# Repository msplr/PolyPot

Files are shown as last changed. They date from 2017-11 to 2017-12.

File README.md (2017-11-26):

# PolyPot Smart Flower Pot

PolyPot is the result of a semester project from the course *Products Design & System Engineering*.
PolyPot is a connected flower pot that automatically waters your plant and lets you monitor it's health remotely.

The microcontroller is an ESP32 and it has sensors for soil moisture, temperature, luminosity and water level connected to it.

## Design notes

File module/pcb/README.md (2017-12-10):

# PolyPot Control Module PCB

## Issues

- Button gpio 23 does not allow wakeup from deepsleep -> connect to IO15
- Soil moisture sensor pinout is wrong. FIX THE CABLE BEFORE CONNECTING!
- IO12 is not connected to SENSOR_ENn PMOS (typo in signal name)
- IO12 must not be pulled up during boot -> use IO25
- R1 and R11 need to be ~120 Ohm to have higher LED brightness
- Footprint of buttons RESET and PROG is too small

## Images
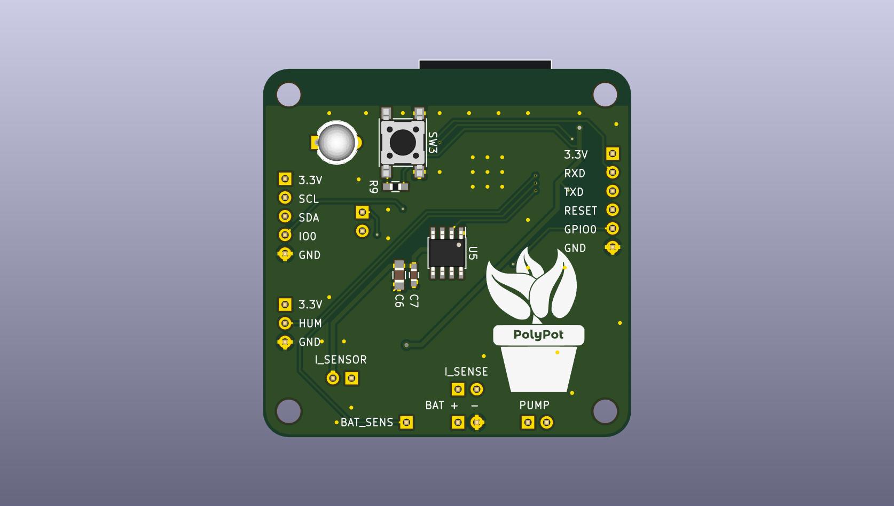
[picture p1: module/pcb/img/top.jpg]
Board Top

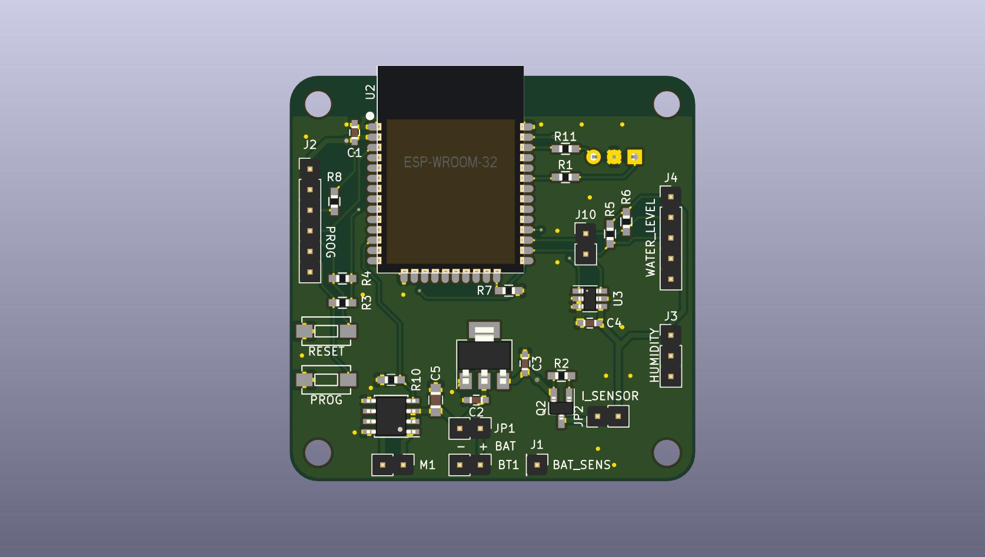
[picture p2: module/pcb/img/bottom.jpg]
Board Bottom

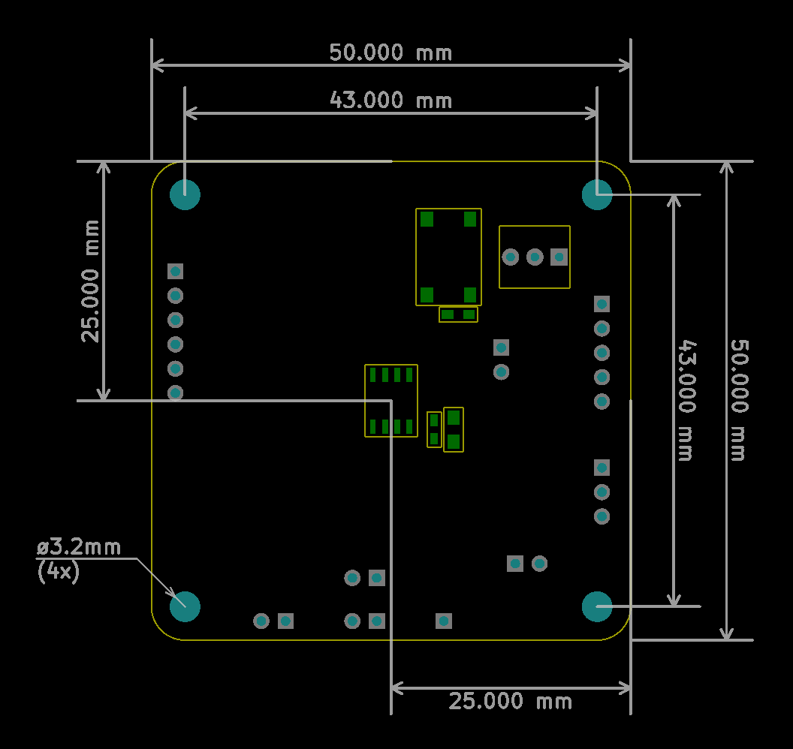
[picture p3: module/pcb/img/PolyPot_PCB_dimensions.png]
Board Dimensions


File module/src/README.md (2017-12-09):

# PolyPot control module source code

## Deploying the code

Copy all necessary modules to the folder `/micropython-esp32/ports/esp32/modules/` in the micropython-esp32 repository.
Then rebuild the firmware:
```
make
make erase
make deploy
```

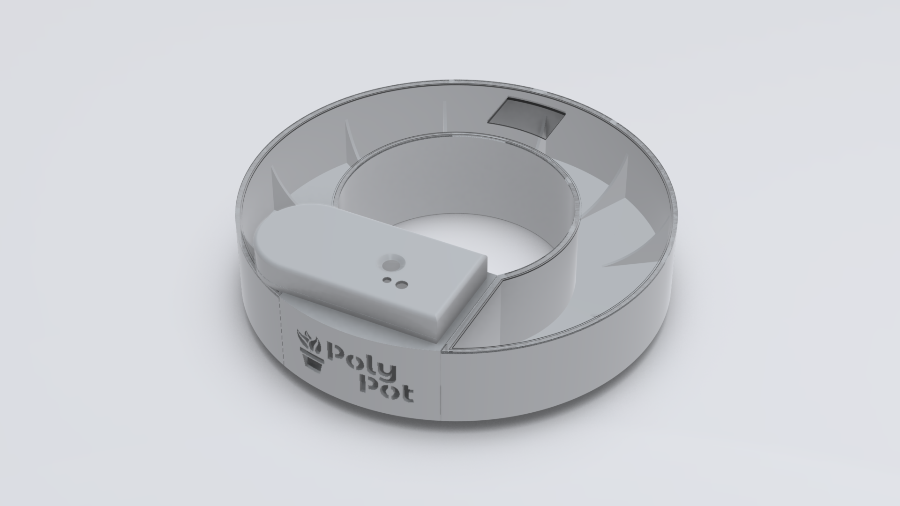
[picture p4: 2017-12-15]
mechanical/solidworks/POLYPOT.png

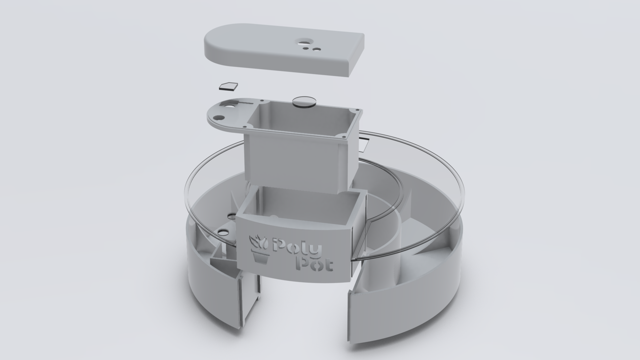
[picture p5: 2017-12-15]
mechanical/solidworks/POLYPOT_EXPLODED.png

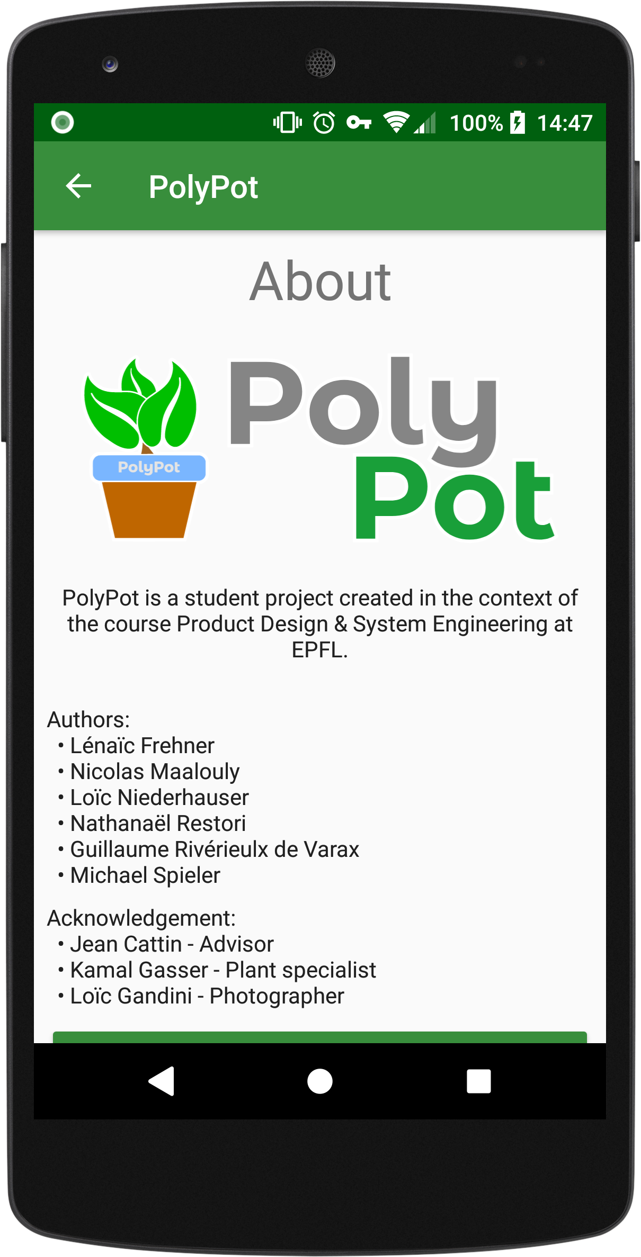
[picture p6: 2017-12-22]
graphics/screenshots/about.png

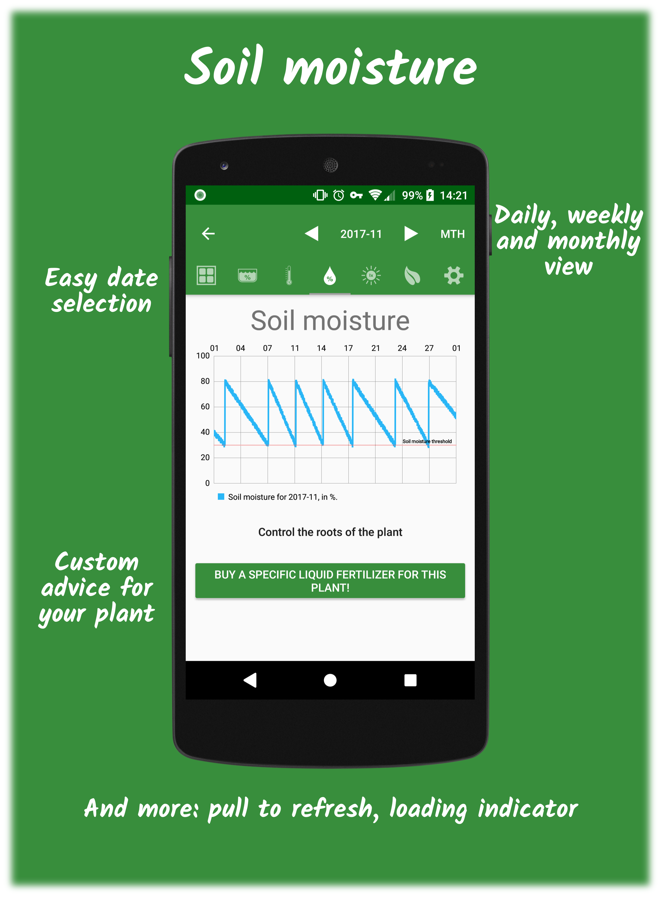
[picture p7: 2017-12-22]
graphics/screenshots/features_soil_moisture.png

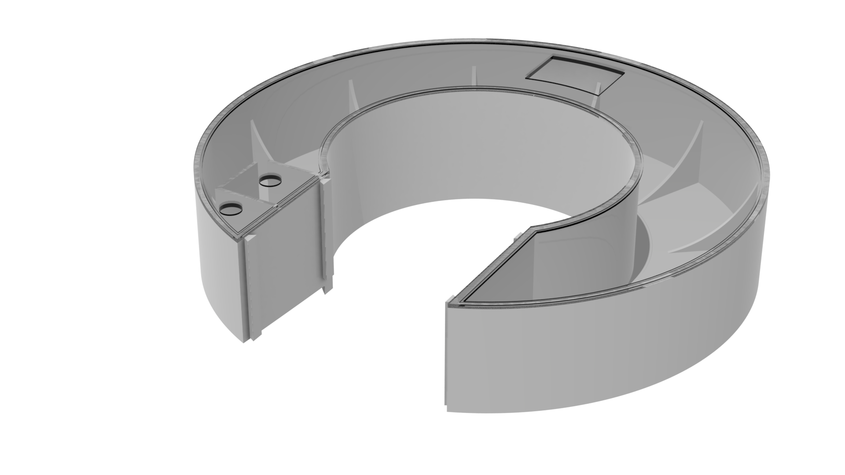
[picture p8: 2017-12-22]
graphics/rendering/water_tank.png

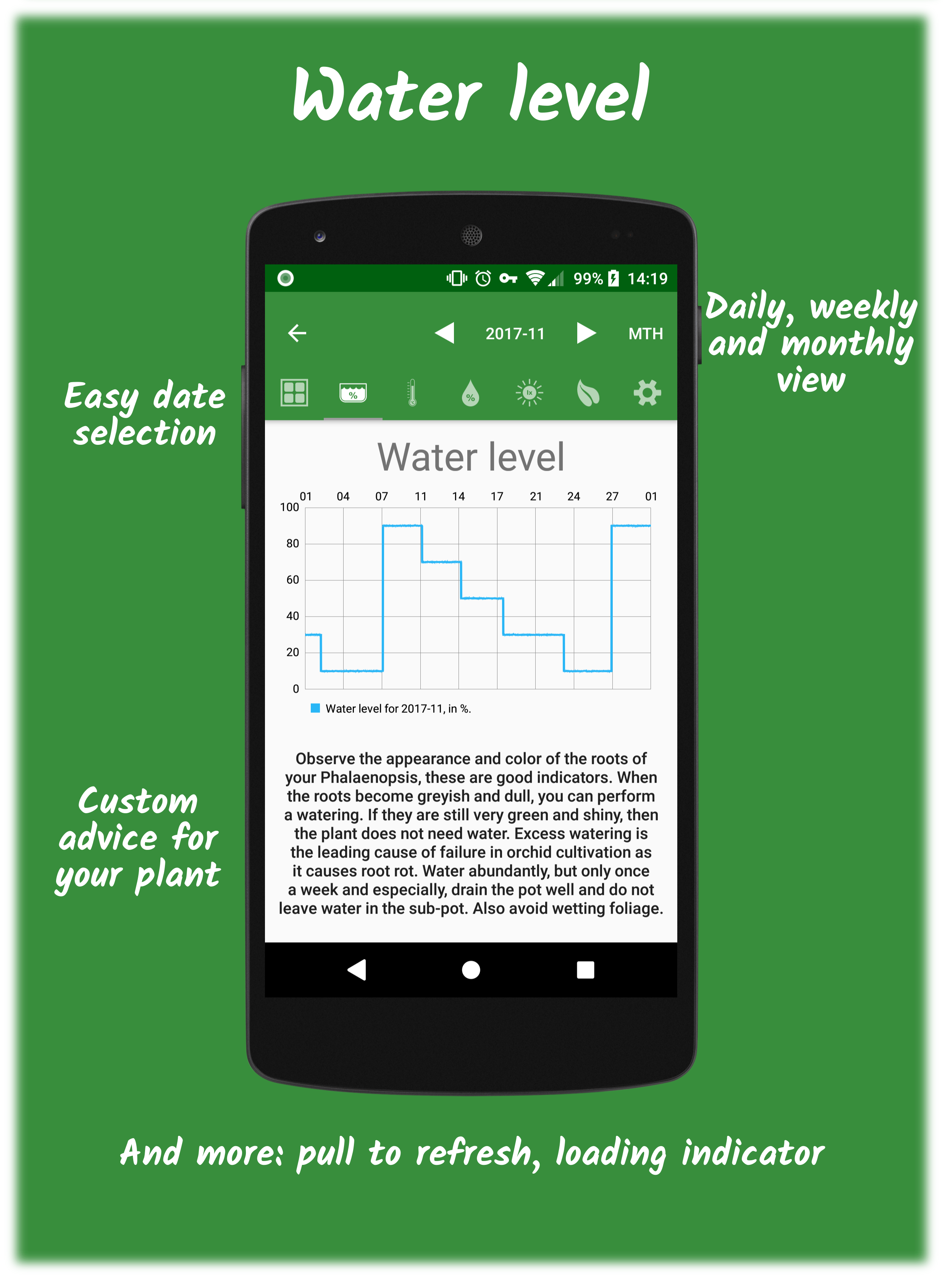
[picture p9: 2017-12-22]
graphics/screenshots/features_water_level.png

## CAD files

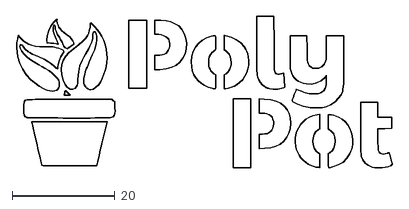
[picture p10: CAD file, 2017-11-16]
mechanical/dxf/logo-title-CAD.dxf
73.3 x 29.7

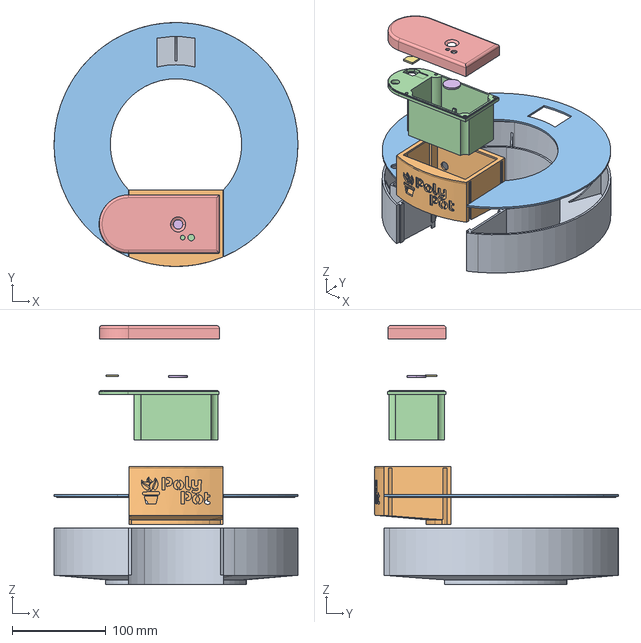
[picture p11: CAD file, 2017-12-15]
mechanical/step/POLYPOT_EXPLODED.stp
260.0 x 259.9 x 276.0 mm

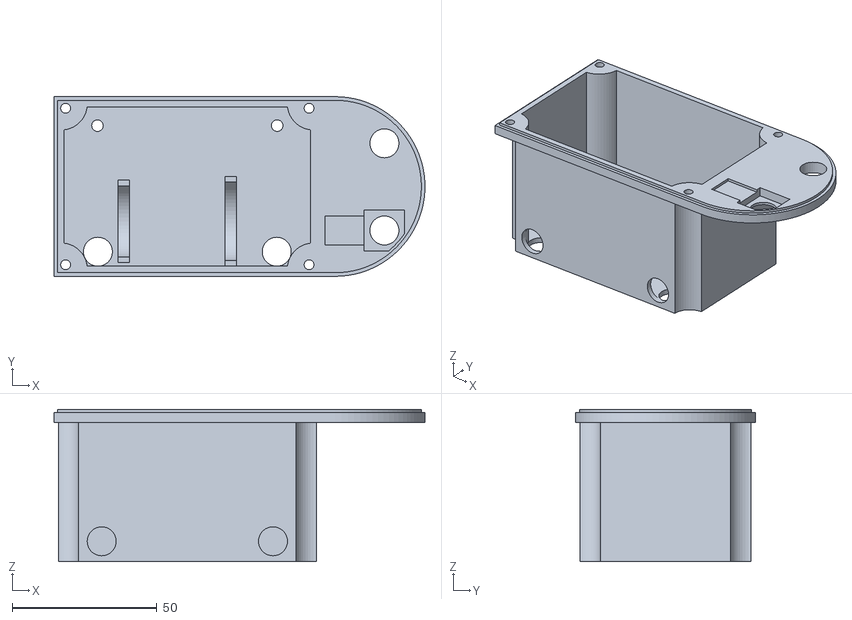
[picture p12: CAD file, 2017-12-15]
mechanical/stl/MODULE.stl
128.0 x 62.0 x 52.5

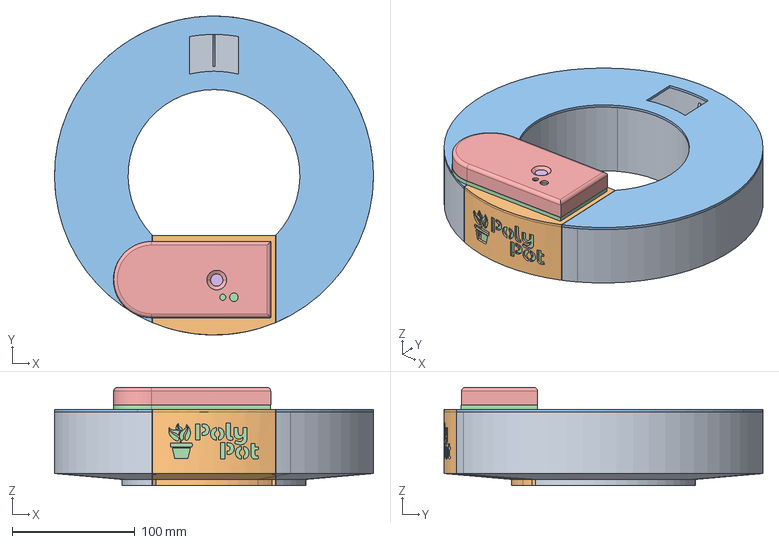
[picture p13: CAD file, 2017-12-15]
mechanical/step/POLYPOT.stp
260.0 x 260.0 x 80.0 mm

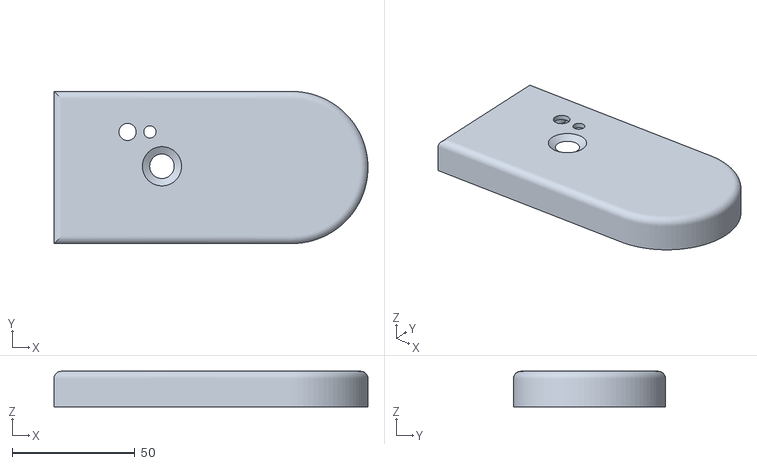
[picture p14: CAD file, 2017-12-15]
mechanical/stl/MODULE_LID.stl
128.0 x 62.0 x 14.5

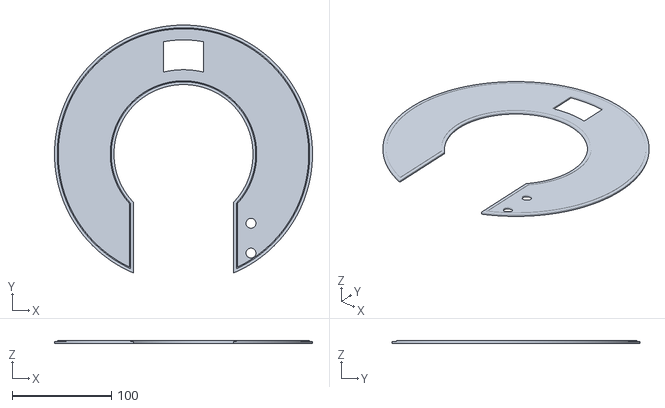
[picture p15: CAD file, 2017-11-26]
mechanical/stl/LID.stl
260.0 x 249.8 x 3.00

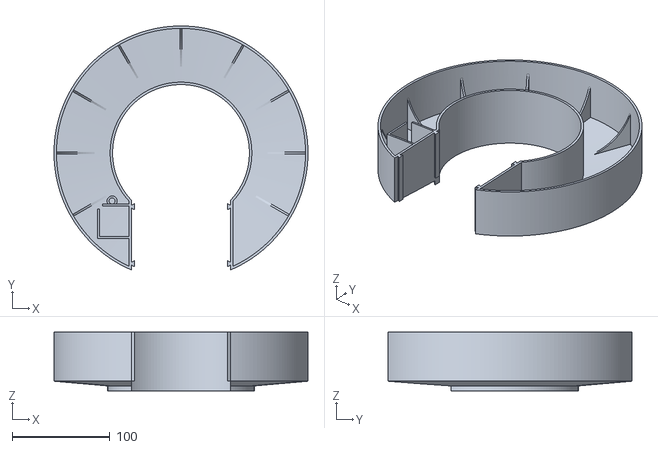
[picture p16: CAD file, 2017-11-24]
mechanical/stl/WATER_TANK.stl
260.0 x 249.8 x 60.0

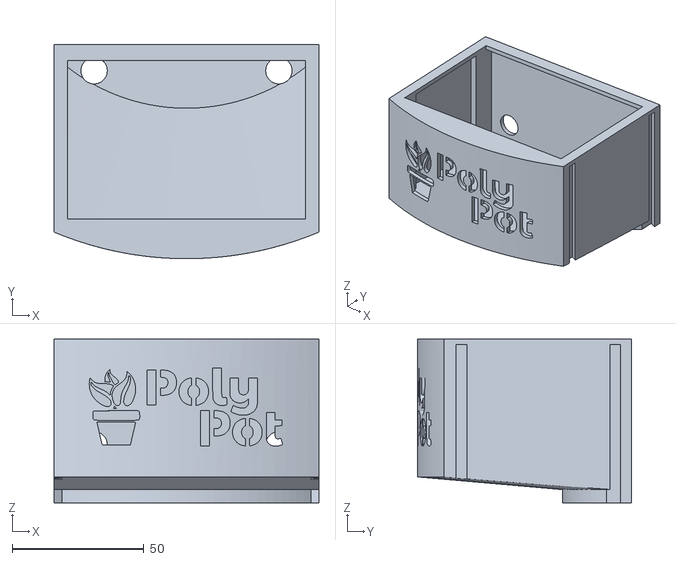
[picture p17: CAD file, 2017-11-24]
mechanical/stl/ADAPTER.stl
100.4 x 81.2 x 62.0

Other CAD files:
mechanical/catia/ADAPTER.CATPart
mechanical/catia/LID.CATPart
mechanical/catia/MODULE.CATPart
mechanical/catia/MODULE_LID.CATPart
mechanical/catia/POLYPOT.CATProduct
mechanical/catia/POLYPOT_EXPLODED.CATProduct
mechanical/catia/WATER_TANK.CATPart
mechanical/catia/WINDOW_LUMINOSITY.CATPart
mechanical/catia/WINDOW_TOF.CATPart
mechanical/dxf/LID.dxf

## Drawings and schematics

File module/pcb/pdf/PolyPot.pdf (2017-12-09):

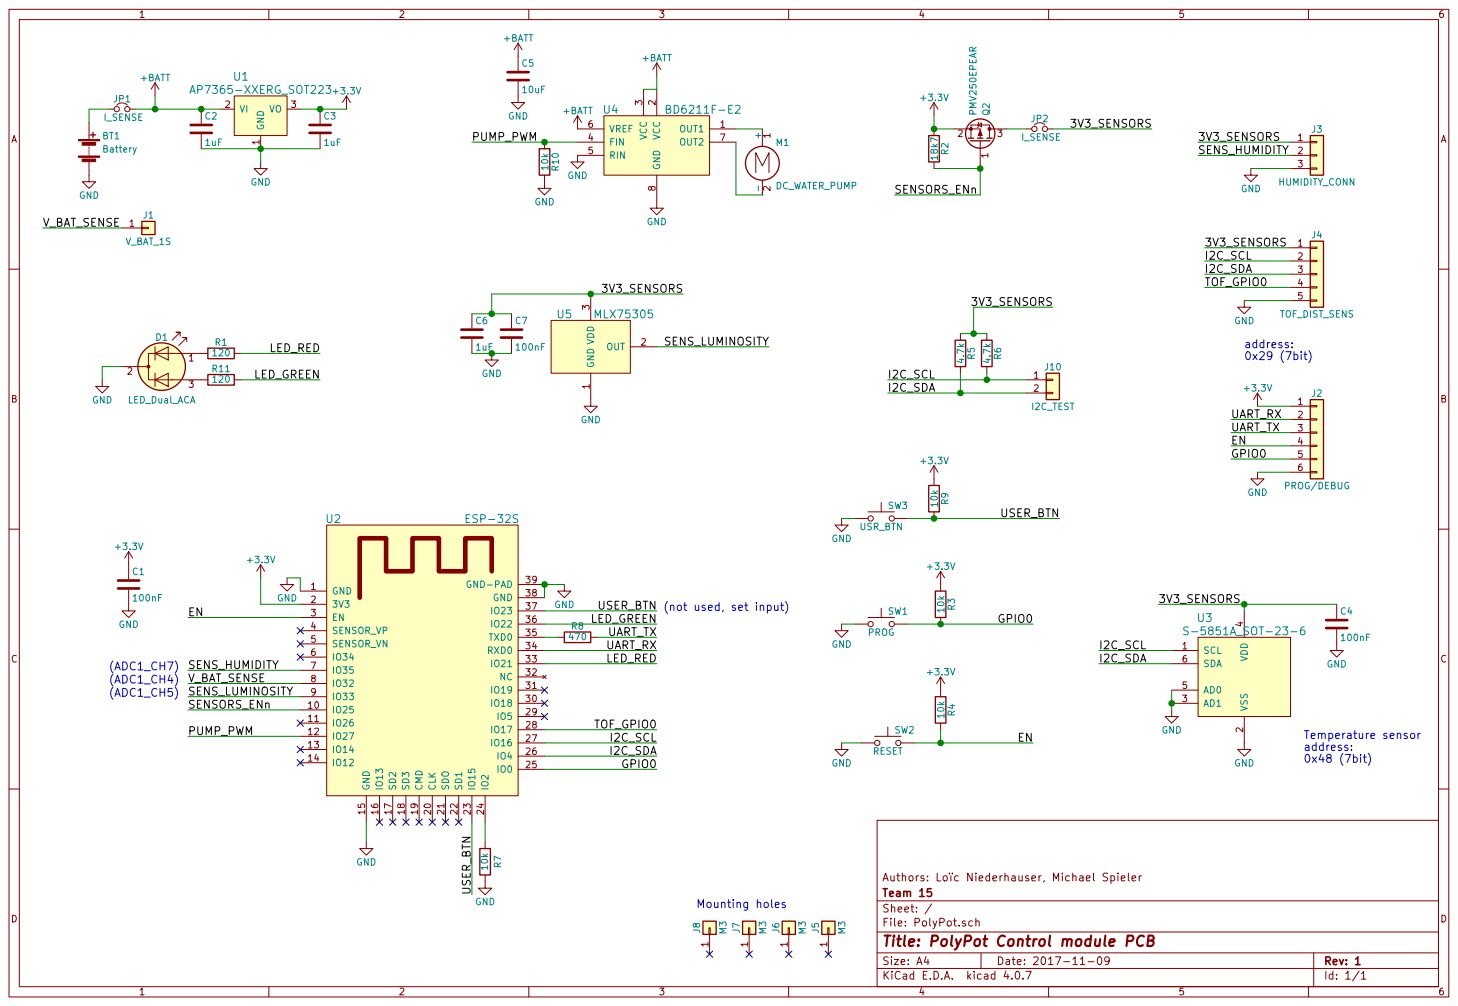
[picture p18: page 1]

3 FIN 4 RIN 5 VREF 6 OUT2 7 GND

(not used, set input)

File: PolyPot.sch Sheet: / Team 15 Authors: Loïc Niederhauser, Michael Spieler

Id: 1/1 Title: PolyPot Control module PCB

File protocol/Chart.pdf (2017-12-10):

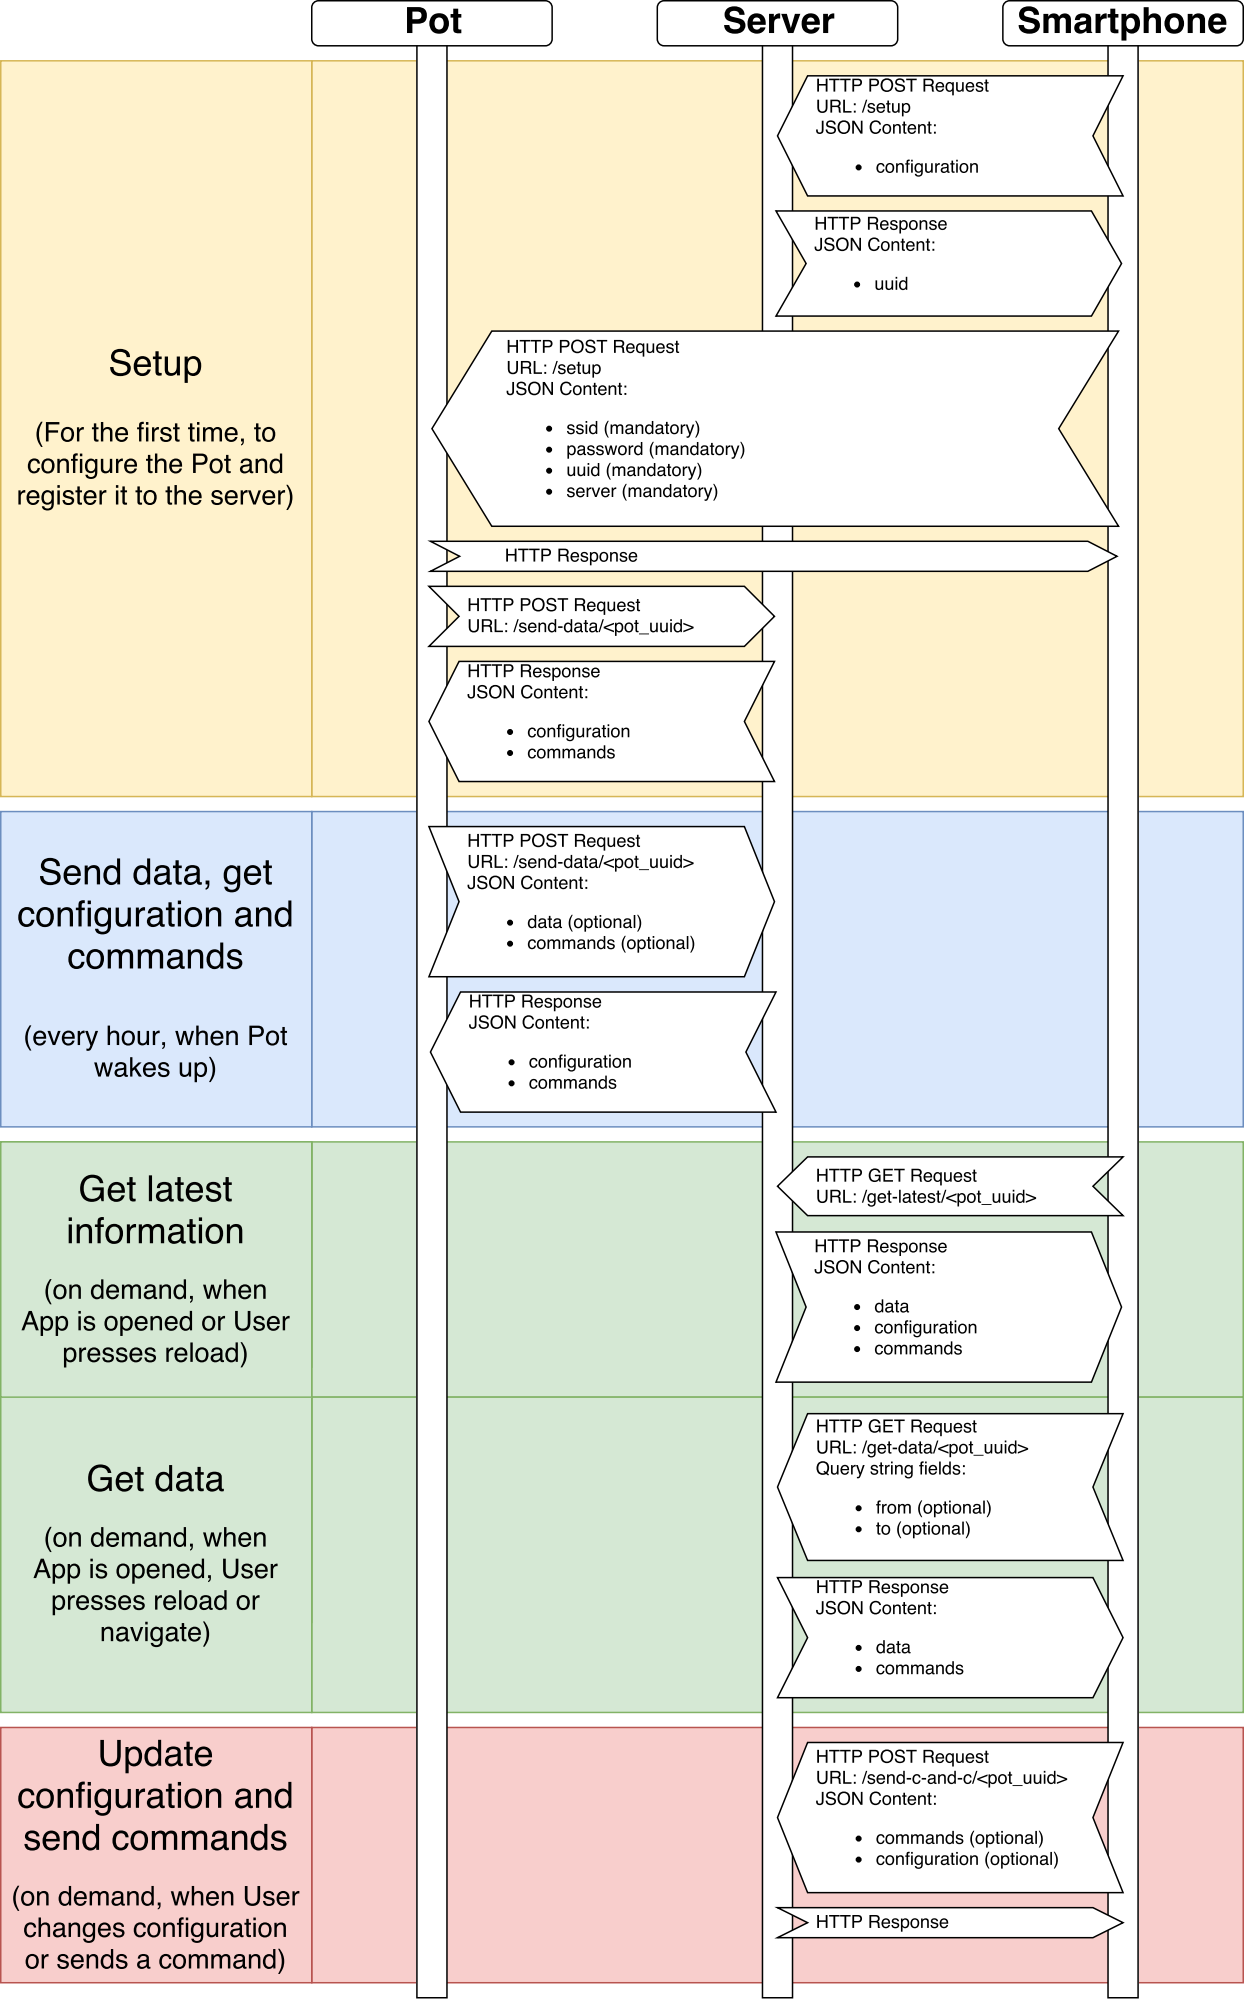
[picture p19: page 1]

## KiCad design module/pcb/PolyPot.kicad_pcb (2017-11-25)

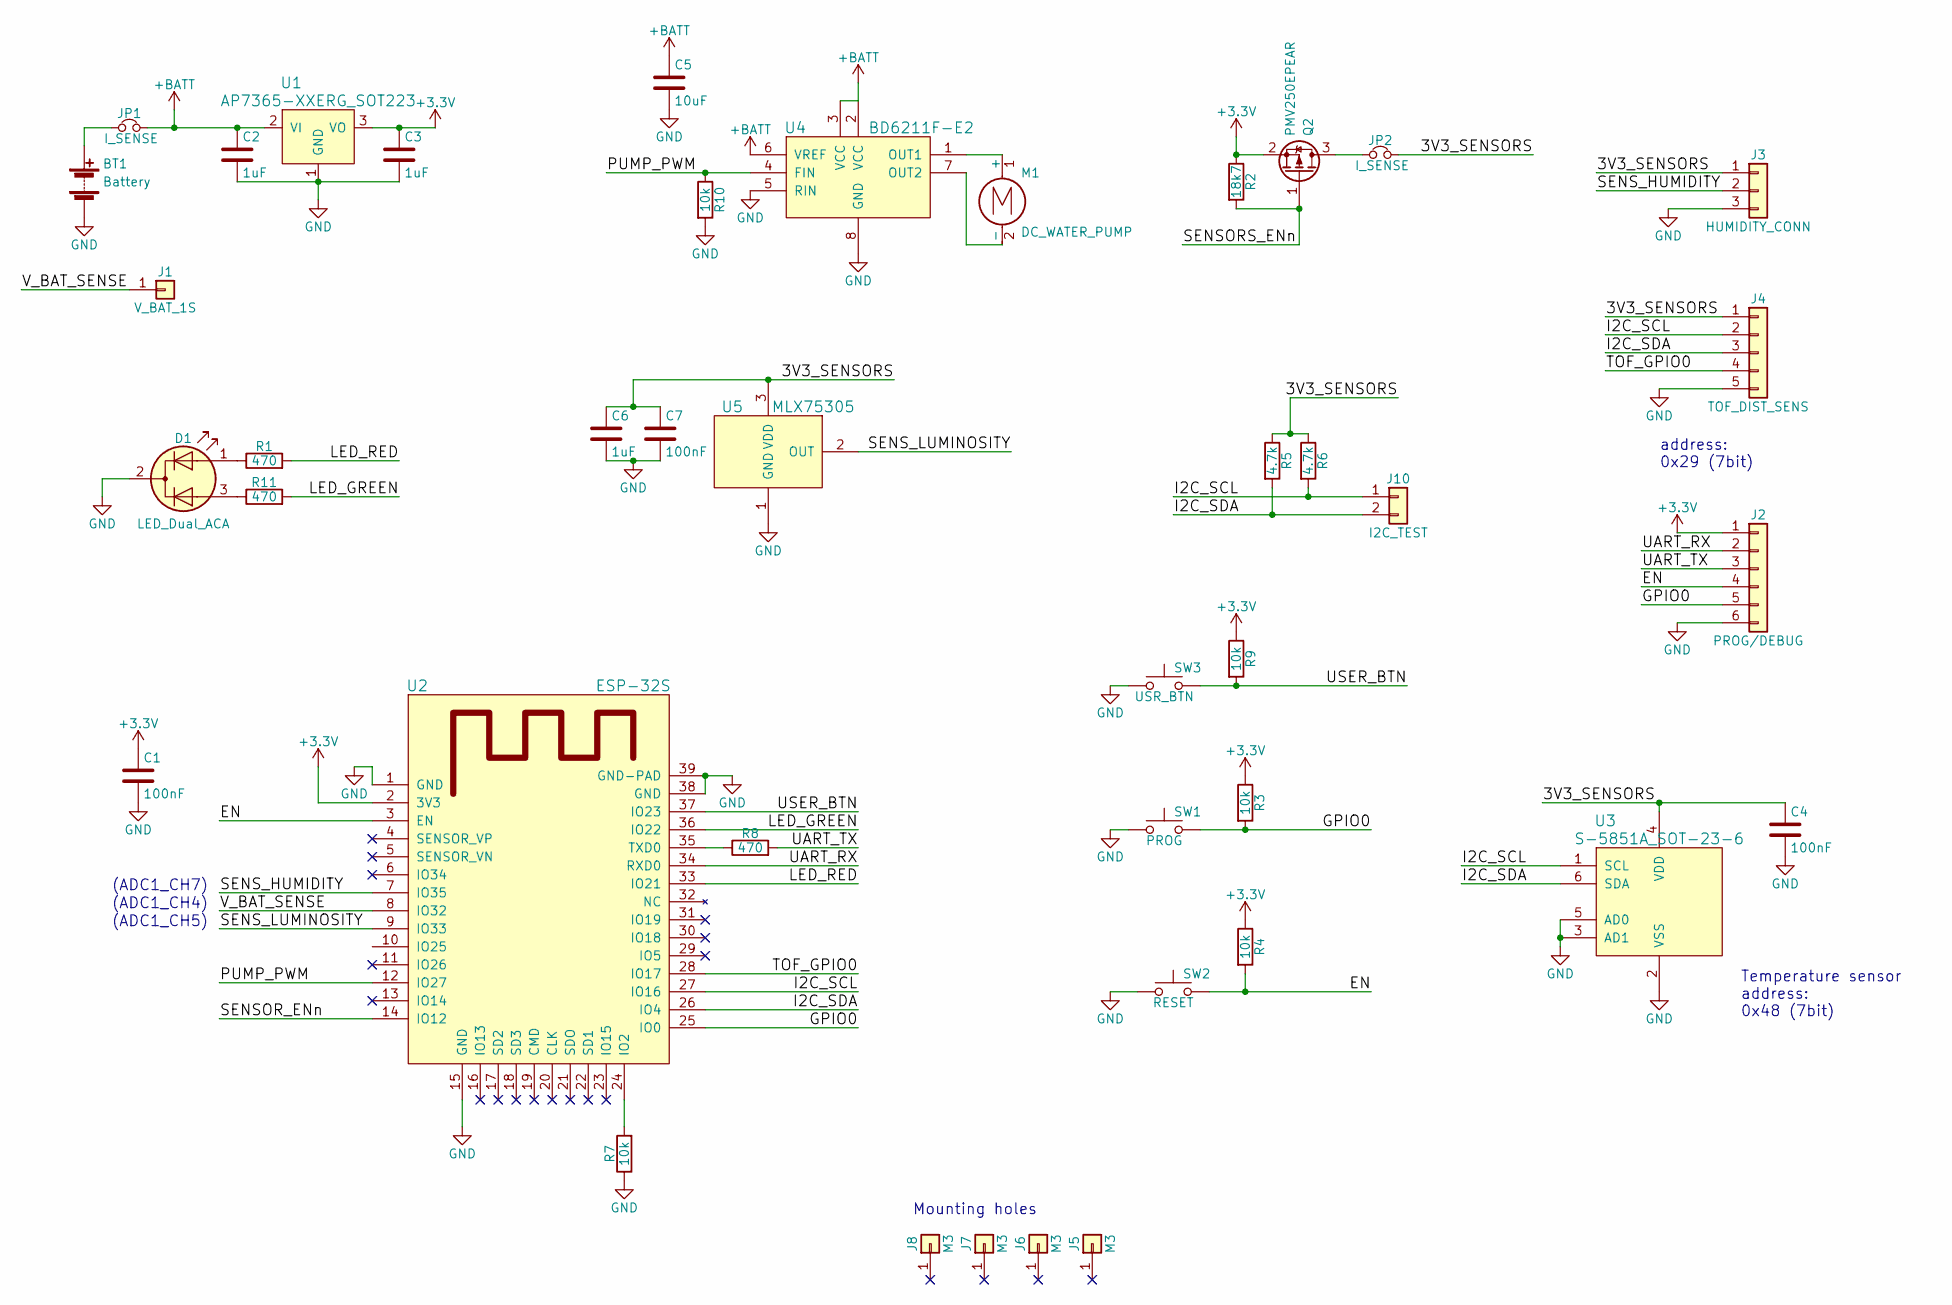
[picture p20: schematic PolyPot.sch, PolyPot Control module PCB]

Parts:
BT1: Battery; Pin_Header_Straight_1x02_Pitch2.54mm
C1, C4, C7: 100nF; C_0603_HandSoldering
C2, C3: 1uF; C_0603_HandSoldering
C5: 10uF; C_0805_HandSoldering
C6: 1uF; C_0805_HandSoldering
D1: LED_Dual_ACA; LED_D5.0mm-3
J1: V_BAT_1S; Pin_Header_Straight_1x01_Pitch2.54mm
J2: PROG/DEBUG; Pin_Header_Straight_1x06_Pitch2.54mm
J3: HUMIDITY_CONN; Pin_Header_Straight_1x03_Pitch2.54mm
J4: TOF_DIST_SENS; Pin_Header_Straight_1x05_Pitch2.54mm
J5, J6, J7, J8: M3; MountingHole_3.2mm_M3
J10: I2C_TEST; Pin_Header_Straight_1x02_Pitch2.54mm
JP1, JP2: I_SENSE; Pin_Header_Straight_1x02_Pitch2.54mm
M1: DC_WATER_PUMP; Pin_Header_Straight_1x02_Pitch2.54mm
Q2: PMV250EPEAR; SOT-23_Handsoldering
R1, R8, R11: 470; R_0603_HandSoldering
R2: 18k7; R_0603_HandSoldering
R3, R4, R7, R9, R10: 10k; R_0603_HandSoldering
R5, R6: 4.7k; R_0603_HandSoldering
SW1: PROG; SW_SPST_EVQPE1
SW2: RESET; SW_SPST_EVQPE1
SW3: USR_BTN; SW_SPST_PTS645
U1: AP7365-XXERG_SOT223; SOT-223
U2: ESP-32S
U3: S-5851A_SOT-23-6; SOT-23-6_Handsoldering
U4: BD6211F-E2; SOIC-8_3.9x4.9mm_Pitch1.27mm
U5: MLX75305; SOIC-8_3.9x4.9mm_Pitch1.27mm

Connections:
+3V3: C1.1, C3.1, J2.1, Q2.2 (S), R2.1, R3.1, R4.1, R9.1, U1.3 (VO), U2.2 (3V3)
+BATT: C2.1, C5.1, JP1.2, U1.2 (VI), U4.2 (VCC), U4.3 (VCC), U4.6 (VREF)
/3V3_SENSORS: C4.1, C6.1, C7.1, J3.1, J4.1, JP2.2, R5.1, R6.1, U3.4 (VDD), U5.3 (VDD)
/EN: J2.4, R4.2, SW2.2, U2.3 (EN)
/GPIO0: J2.5, R3.2, SW1.2, U2.25 (IO0)
/I2C_SCL: J4.2, J10.1, R6.2, U2.27 (IO16), U3.1 (SCL)
/I2C_SDA: J4.3, J10.2, R5.2, U2.26 (IO4), U3.6 (SDA)
/LED_GREEN: R11.2, U2.36 (IO22)
/LED_RED: R1.2, U2.33 (IO21)
/PUMP_PWM: R10.1, U2.12 (IO27), U4.4 (FIN)
/SENSORS_ENn: Q2.1 (G), R2.2
/SENS_HUMIDITY: J3.2, U2.7 (IO35)
/SENS_LUMINOSITY: U2.9 (IO33), U5.2 (OUT)
/TOF_GPIO0: J4.4, U2.28 (IO17)
/UART_RX: J2.2, U2.34 (RXD0)
/UART_TX: J2.3, R8.2
/USER_BTN: R9.2, SW3.2, U2.37 (IO23)
/V_BAT_SENSE: J1.1, U2.8 (IO32)
GND: BT1.2 (-), C1.2, C2.2, C3.2, C4.2, C5.2, C6.2, C7.2, D1.2 (K), J2.6, J3.3, J4.5, R7.1, R10.2, SW1.1, SW2.1, SW3.1, U1.1 (GND), U2.1 (GND), U2.15 (GND), U2.38 (GND), U2.39 (GND-PAD), U3.2 (VSS), U3.3 (AD1), U3.5 (AD0), U4.5 (RIN), U4.8 (GND), U5.1 (GND)
unnamed: BT1.1 (+), JP1.1
unnamed: D1.1 (A1), R1.1
unnamed: D1.3 (A2), R11.1
unnamed: JP2.1, Q2.3 (D)
unnamed: M1.1 (+), U4.1 (OUT1)
unnamed: M1.2 (-), U4.7 (OUT2)
unnamed: R7.2, U2.24 (IO2)
unnamed: R8.1, U2.35 (TXD0)

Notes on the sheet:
address: 0x29 (7bit)
Temperature sensor address: 0x48 (7bit)
Mounting holes
(ADC1_CH4)
(ADC1_CH5)
(ADC1_CH7)

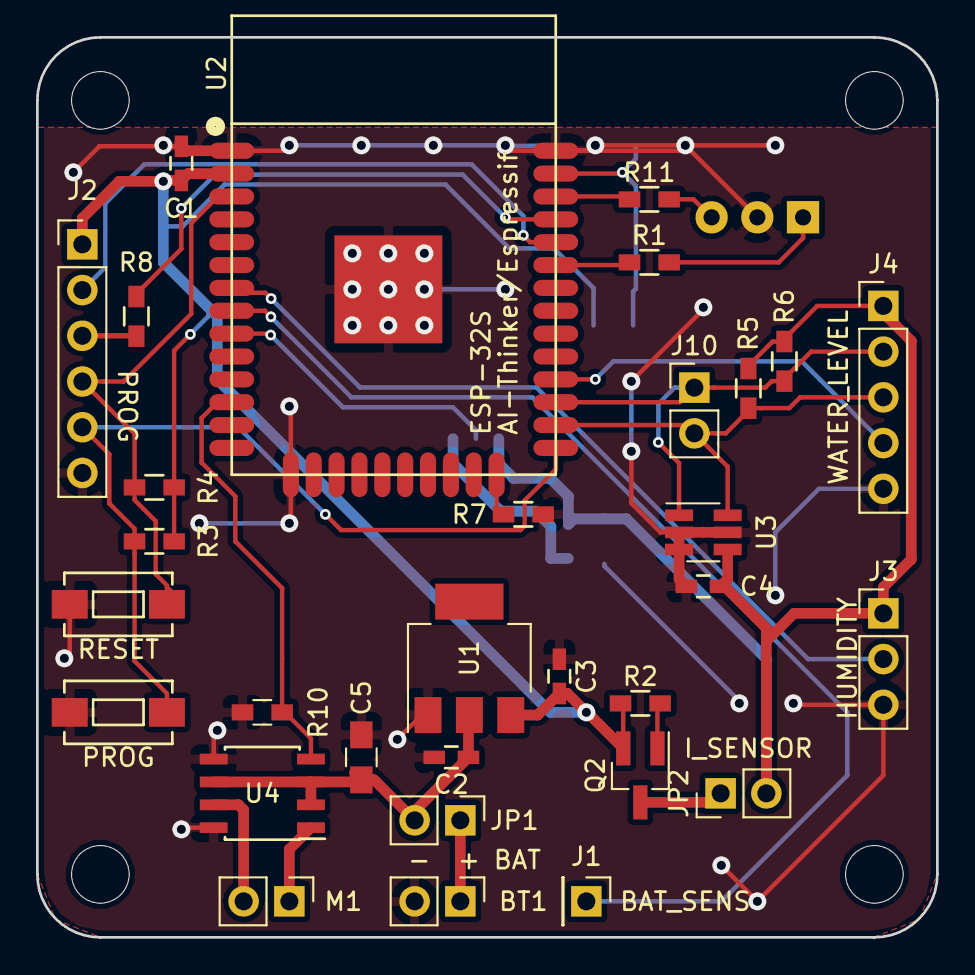
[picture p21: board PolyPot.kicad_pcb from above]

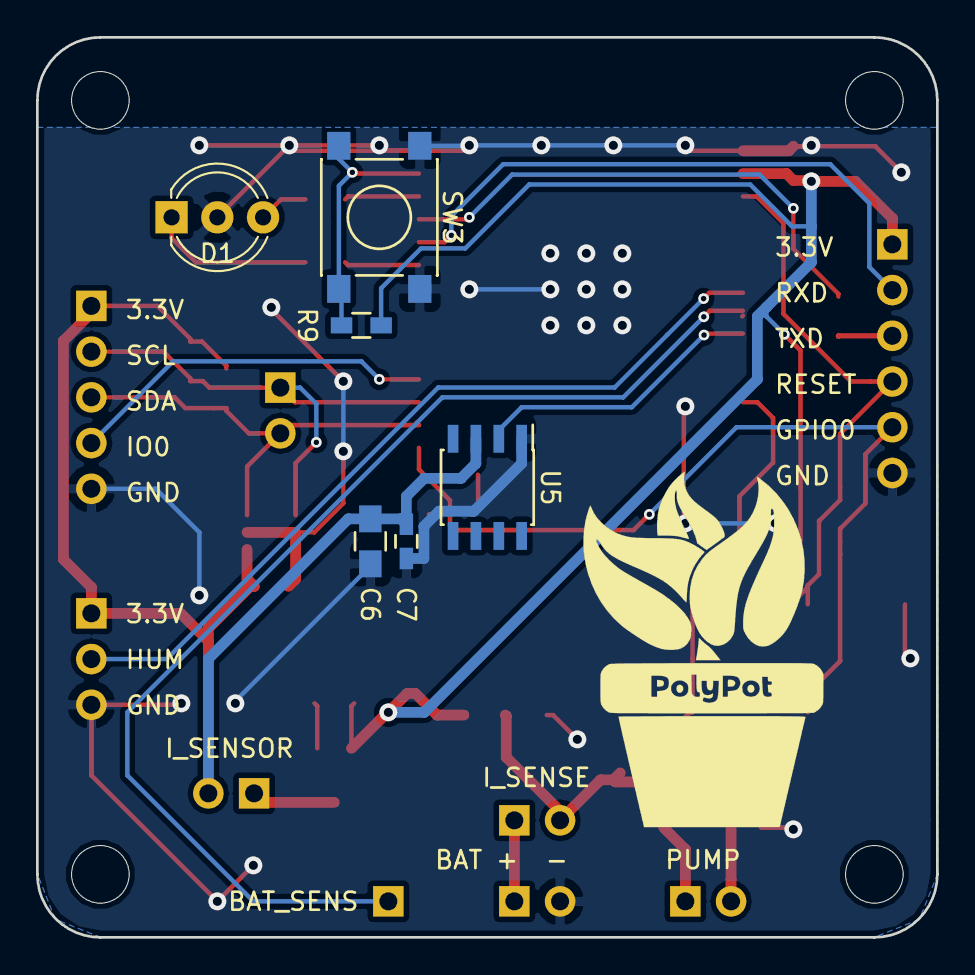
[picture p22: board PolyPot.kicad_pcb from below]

Board: 2 copper layers, 50.0 x 50.0 mm, 41 parts (6 on the bottom side), 27 nets.

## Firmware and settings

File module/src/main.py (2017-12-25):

import machine
import communication
import board
import sensors
import utime
import permmem
import embeded_ntptime as ntptime

# Variables with no flash storage needed
REBOOT_TIME        = const(5)       # Delay before waking up after a reboot in seconds
SENSORS_START_TIME = const(1)       # Delay needed by the sensors to available in seconds
PUMP_FLOW          = const(50)      # Average pump flow in [ml/s]
filename           = "log.txt"      # File storing the parameters in flash memory
reinit             = False          # If the module has been reinitialised
first_boot         = False          # If this is the first boot
server_connect     = False          # If a server connection is required at this point
contact            = False          # If the module successfully contacted the server
single_data        = {}             # Structure for a single data point
single_command     = {}             # Structure for a single command
master_dict        = {}             # A dictionnary to simplify witting data in a file
suffix_send        = "/send-data/"  # Extension of the url to send data to the server

def variables_init():
    master_dict  = {} # A master dictionary to help writing and reading data in flash memory
    wakeup_count = 0  # Number of wake-ups since the last wifi connection
    data         = [] # Array destined to collect the data points
    commands     = [] # Array destined to collect the executed commands
    received_cmd = [] # Array destined to collect the commands sent by the server
    return master_dict, wakeup_count, data, commands, received_cmd

#____________________________________________________________________________________________________
#_____________________________________________MAIN_CODE______________________________________________
try:
    # Checking if there are already data in flash memory or if there's a reinitilization
    try:
        master_dict = permmem.read_in_flash(filename)
    except OSError:
        print('First boot.\n')
        first_boot = True
    else:
        if not machine.wake_reason() == machine.PIN_WAKE:
            print('Normal wakeup. Booting data:\n')
            print(master_dict)
            board.led_green()
            wakeup_count, data, commands, received_cmd, url_send, wifi_param, config = permmem.open_dict(master_dict)
        else:
            reinit = True

    # Initialisation if needed
    if reinit or first_boot:
        print('Initialise.\n')
        board.led_red()
        master_dict, wakeup_count, data, commands, received_cmd = variables_init()

        # Module initialisation
        while not contact:
            wlan, wifi_param = communication.new_connection()
            print("First connection\n")
            url_send = wifi_param["server"] + suffix_send + wifi_param["uuid"]
            print("URL generated\n")
            print(url_send)

            #Tries to contact server
            try:
                config, received_cmd = communication.send_data(url_send)
            except:
                print("WARNING: Couldn't reach server, will try again.\n")
            else:
                contact = True
                print("New config and command:\n")
                print(received_cmd)
                print(config)
            communication.wifi_disconnect(wlan)

    # Check if Wifi shall be activated, and activates it if needed and possible
    if wakeup_count*config["logging_interval"] >= config["sending_interval"]:
        wlan = communication.wifi_init()
        print("Trying a normal connection.\n")
        co_status = communication.wifi_connect(wifi_param, wlan)
        if co_status:
            print("Normal connection OK.\n")
            try:
                config, received_cmd = communication.send_data(url_send)
            except:
                board.led_red()
                communication.wifi_disconnect(wlan)
            else:
                server_connect = True
        else:
            print("Normal connection failed, reported the sendig to the next wakeup.\n")
            board.led_red()

    # Reading sensors
    sensors.start()
    print("Wait for sensor start\n")
    utime.sleep(SENSORS_START_TIME)
    print('Read sensors.\n')
    single_data = sensors.read_all()
    print("Reading done.\n")
    sensors.stop()


    # Updating time
    print("Formating time.\n")
    time=utime.localtime()
    time_iso='{}-{}-{}T{}:{}:{}Z'.format(time[0], time[1], time[2], time[3], time[4], time[5])
    single_data["datetime"] = time_iso
    print("Time done.\n")
    print(single_data)

    # Saving the data
    data.append(single_data)
    print("Data saved.\n")
    # Computing the watering time:
    water_time = int(config["water_volume_pumped"] / PUMP_FLOW)

    # Treating the commands
    if len(received_cmd)>0:
        for cmd in received_cmd:
            print('water plant')
            board.water_pump.on()
            utime.sleep(water_time)  # TODO: Empiracaly adjust the time
            board.water_pump.off()
            cmd["status"]   = "executed"
            cmd["datetime"] = time_iso
            print("Finished water")
            commands.append(cmd)
        received_cmd = []
        print("Commands cleared")
    else:
        # Trigering automatic watering if needed and no commands done
        if data['soil_moisture']<config["target_soil_moisture"]:
            print("Starting automatic watering.\n")
            board.water_pump.on()
            utime.sleep(water_time)
            board.water_pump.off()
            print("Automatic watering done.\n")
            single_command = {"type":"water","status":"executed","datetime":time_iso}
            commands.append(single_command)
            single_command = {}
            print("Command saved.\n")

    # Sending the data and executed commands if required
    if server_connect:
        print("Second Connection to sever.\n")
        try:
            config, received_cmd = communication.send_data(url_send,data=data,commands=commands)
        except:
            board.led_red()
            print("Data sending failed, reporting the sending to next connection.\n")
            utime.sleep(communication.TIME_LED_FLASH)
        else:
            data = []
            commands = []
            wakeup_count = 0
            print("Data sending done.\n")
        finally:
            communication.wifi_disconnect(wlan)

    wakeup_count += 1
    print("Building the master dictionnary.\n")
    master_dict = permmem.create_dict(wakeup_count, data, commands, received_cmd, url_send, wifi_param, config)

    # Flash storage:
    print("Starting flash storage.\n")
    try:
        permmem.delete_file(filename)
    except:
        if not first_boot:
            print("WARNING: The log file couldn't be erased. This might lead to further errors\n")
    try:
        permmem.write_in_flash(filename, master_dict)
    except:
        print("ERROR: failure to write in flash, deleting data.\n")
        master_dict  = {}
        data         = []
        received_cmd = {}
        master_dict  = permmem.create_dict(wakeup_count, data, commands, received_cmd, url_send, wifi_param, config)
        try:
            print("Retrying to write in flash.\n")
            permmem.write_in_flash(filename, master_dict)
        except:
            print("FATAL ERROR: Couldn't write in flash. Full reboot.\n")

    # Returning to sleep
    print('Go to deepseleep.\n')
    board.led_off()
    board.sleep(config["logging_interval"])

# Fatal error mode
except:
    print("FATAL ERROR: Unexpected error. Rebooting the system.\n")
    board.led_off()
    sensors.stop()
    try:
        permmem.delete_file(filename)
    except:
        print ("No log file, ready to reboot.\n")
    else:
        print ("Deleted log file, ready to reboot.\n")
    finally:
        print("REBOOTING.\n")
        board.sleep(REBOOT_TIME)

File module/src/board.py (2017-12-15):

import machine
import esp32

# wakeup from pin 23 not possible
# fix: wire from pin 23 to pin 15

def sleep(sec):
    button = machine.Pin(23, machine.Pin.IN)
    button = machine.Pin(15)
    button.init(machine.Pin.IN, machine.Pin.PULL_UP)
    esp32.wake_on_ext0(button, level=0)
    machine.deepsleep(1000*sec)


green_led_pin = machine.Pin(22, machine.Pin.OUT)
red_led_pin = machine.Pin(21, machine.Pin.OUT)

def led_green():
    green_led_pin.value(1)
    red_led_pin.value(0)

def led_orange():
    green_led_pin.value(1)
    red_led_pin.value(1)

def led_red():
    green_led_pin.value(0)
    red_led_pin.value(1)

def led_off():
    green_led_pin.value(0)
    red_led_pin.value(0)

button_pin = machine.Pin(15, machine.Pin.IN)

def button():
    if button_pin.value() == 0:
        return True
    else:
        return False

class Pump():
    """Water Pump class"""
    def __init__(self, pin):
        self.pin = pin
        self.pin.init(machine.Pin.OUT)
        self.off()

    def on(self):
        self.pin.value(1)

    def off(self):
        self.pin.value(0)

pump_pin = machine.Pin(27)
water_pump = Pump(pump_pin)

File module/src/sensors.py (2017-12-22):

import struct
import machine
import VL6180X
import time

SENSOR_ENn = machine.Pin(25, machine.Pin.OUT)

def power_enable():
    SENSOR_ENn.value(0)

def power_disable():
    SENSOR_ENn.value(1)

i2c = machine.I2C(scl=machine.Pin(16), sda=machine.Pin(4), freq=100000)
i2c.scan()

moist_pin = machine.Pin(35, machine.Pin.IN)
moist_adc = machine.ADC(moist_pin) # ADC1 CH 7
moist_adc.atten(machine.ADC.ATTN_11DB)

def moisture():
    """Read the moisture sensor voltage"""
    return 3.3 * moist_adc.read()/1023

battery_pin = machine.Pin(32, machine.Pin.IN)
battery_adc = machine.ADC(battery_pin) # ADC1 CH 4
battery_adc.atten(machine.ADC.ATTN_11DB)

def battery_voltage():
    """Read the total battery voltage"""
    return 3 * 3.3 * battery_adc.read()/1023

luminosity_pin = machine.Pin(33, machine.Pin.IN)
luminosity_adc = machine.ADC(luminosity_pin) # ADC1 CH 5
luminosity_adc.atten(machine.ADC.ATTN_11DB)

LUMINOSITY_GAIN = 6/0.07 # [Lux/V]

def luminosity():
    """Read the luminosity sensor in Lux (approximatively)."""
    return 3.3 * luminosity_adc.read()/1023 * LUMINOSITY_GAIN

TOF_ADDR = 41
TOF_RESETn = machine.Pin(17, machine.Pin.OUT)
tof = VL6180X.VL6180X(i2c, TOF_RESETn)
DIST_FULL = 20
DIST_EMPTY = 118

def water_level():
    """Read water level in percent."""
    dist = tof.distance()
    level = 100*(dist - DIST_EMPTY)/(DIST_FULL - DIST_EMPTY)
    if level > 100.0:
        level = 100.0
    elif level < 0.0:
        level = 0.0
    return level

TEMP_ADDR = 72

def temperature():
    """Read temperature in deg Celsius."""
    i2c.writeto_mem(TEMP_ADDR, 0x01, b'\x00') # write control register, enable
    temp = i2c.readfrom_mem(TEMP_ADDR, 0x00, 2)
    temp = struct.unpack('>h', temp) # MSByte first -> 16 bit big endian
    (temp, ) = temp # upack tuple
    temp = temp / 256
    return temp

def start():
    power_enable()
    tof.start()

    addr = i2c.scan()
    # todo: check if all sensor present

def stop():
    tof.stop()
    power_disable()

def read_all():
    data = {}
    data['luminosity'] = luminosity()
    data['soil_moisture'] = moisture()
    #data['battery_level'] = battery_voltage()
    data['battery_level'] = 56
    data['water_level'] = water_level()
    data['temperature'] = temperature()
    return data

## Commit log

2017-11-05 Start working on schematic
    [PolyPot.kicad_pcb, PolyPot.sch]
2017-11-09 Add temperature sensor, V_Bat sense
    [PolyPot.sch]
2017-11-09 Component annotation
    [PolyPot.sch]
2017-11-09 Assign footprints, start with PCB
    [PolyPot.kicad_pcb, PolyPot.sch]
2017-11-09 Add ESP32 3d shape
    [PolyPot.kicad_pcb, PolyPot.sch]
2017-11-09 PCB: rough component placement
    [PolyPot.kicad_pcb, PolyPot.sch]
2017-11-10 Move files related to the module in their own directory
    [PolyPot.kicad_pcb, PolyPot.sch]
2017-11-10 Start server development. Can only manage raw data currently.
2017-11-11 Add command and configuration support to server, update server to current protocol
2017-11-14 Update pin assignment, add user button, add luminosity conn
    [PolyPot.kicad_pcb, PolyPot.sch]
2017-11-16 PCB: update voltage regulator
    [PolyPot.kicad_pcb, PolyPot.sch]
2017-11-16 PCB: updtate local lib
2017-11-16 PCB: 3d model placement
    [PolyPot.kicad_pcb, PolyPot.sch]
2017-11-16 Add logo material
    [logo-title-CAD.dxf]
2017-11-17 First PCB routage+ small correction int the schematics
    [PolyPot.kicad_pcb, PolyPot.sch]
2017-11-17 PCB routage (except for track width to modify)
    [PolyPot.kicad_pcb]
2017-11-20 Minor correction in the schematics
    User_Button was improperly connected. There were two signals (user_button and user_btn) not linked to each other
    [PolyPot.sch]
2017-11-20 Updated track width
    [PolyPot.kicad_pcb]
2017-11-20 Adding footprint and schematics for esp32-s
    This is a GitHub library containing the Ki-Cad schematics and footprints for ESP-32 S, ESP-32-WROOM and ESP32. It also contaains the datasheets necessary to check the pin assignment and wiring.
    [ESP32-Footprints.kicad_pcb, ESP32-Footprints.sch, espressif-xess.csv]
2017-11-20 Replaced ESP32-WROOM with ESP32-S
    [PolyPot.sch]
2017-11-20 New routing using the ESP32-S footprint
    [PolyPot.kicad_pcb]
2017-11-21 Added the PWM driver and routed it on the PCB
    There might be some issues with the path for library for ESP32-S. You might need to respecify the path to "ESP32-footprints-Lib.pretty" in the PCB editor library manager.
    [PolyPot.kicad_pcb, PolyPot.sch]
2017-11-23 PCB: Update footprints, schematic fixes, nicer edge cut, no GND next to antenna
    [ESP32-Footprints.kicad_pcb, ESP32-Footprints.sch, PolyPot.kicad_pcb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]
2017-11-23 PCB: change SOIC-8 footprint
    [PolyPot.kicad_pcb, PolyPot.sch]
2017-11-23 Add logo
    [PolyPot.kicad_pcb, PolyPot.sch]
2017-11-24 PCB: fix 3.3V regulator footprint, connect TOF GPIO0, start routing
    [PolyPot.kicad_pcb, PolyPot.sch]
2017-11-24 PCB: routing almost done, silkscreen text
    [PolyPot.kicad_pcb, PolyPot.sch]
2017-11-24 PCB: ground connection vias
    [PolyPot.kicad_pcb]
2017-11-24 Add mechanical design
    [ADAPTER.CATPart, ADAPTER.stl, LID.CATPart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]
2017-11-24 Move logo and add icons
    [logo-title-CAD.dxf]
2017-11-25 PCB: add luminosity sensor to schematic
    [PolyPot.sch]
2017-11-25 PCB: new routing with luminosity sensor, move LED and button to upper side.
    [PolyPot.kicad_pcb, PolyPot.sch]
2017-11-25 PCB: add dimension drawings
    [PolyPot.kicad_pcb]
2017-11-25 PCB: improve GND connection
    [PolyPot.kicad_pcb]
2017-11-25 PCB: gerber files
    [PolyPot.kicad_pcb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]
2017-11-25 PCB: add images
    [PolyPot.kicad_pcb]
2017-11-25 PCB: schematic pdf
2017-11-25 PCB: datasheets
2017-11-25 PCB: dimensions drawing
2017-11-26 Resolve bugs when switching between tabs, rotating and due to timezone handling
2017-11-26 Correct LID and add assembly
    [LID.CATPart, LID.stl, POLYPOT.CATProduct]
2017-11-27 Small improvements on charts, handle back button, better CommunicationManager + use directly JsonObjectRequest
2017-12-03 Add "Water plant" button, fix setup, add possibility to add a hint in CM Request, use ressources for all dates
2017-12-04 PCB README
2017-12-09 Creating sourcecode file
    Source code for esp32
2017-12-09 More PCB bugs
2017-12-09 Update hardware fixes in schematic
    [PolyPot.sch]
2017-12-09 Sensors and LED test scripts, update io pins
2017-12-09 temperature sensor test
2017-12-09 set moisture sensor gain, TOF sensor enable
2017-12-10 Start working on TOF distance sensor driver
2017-12-10 PCB: Comment about button footprint
2017-12-14 Corrected minor bug and typos
    [main.py]
2017-12-14 Fixed the ntptime
    Should be still checked with a wifi connection
    [main.py]
2017-12-15 test TOF sensor driver
2017-12-15 test TOF sensor notes
2017-12-15 working TOF senosr driver
2017-12-15 update LED module
2017-12-15 pump module
2017-12-15 refactor pin initialization
2017-12-15 put everythin in board and sensors module
2017-12-15 Add module and update assembly
    [LID.dxf, MODULE.CATPart, MODULE.stl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]
2017-12-15 remove pin initialization, import board
2017-12-15 Better connect protocol, fixed serveer com bug
    [communication.py]
2017-12-15 Add sensors readout
2017-12-15 pwm problems, switch to all/nothin pump control
    [board.py]
2017-12-15 Deleted debug prints
2017-12-15 Correcting sensor start
2017-12-15 TOF calibration
2017-12-16 Fixed ntptime offset
    Fixed the 30 years offset given by standard ntptime by adding a embeded_ntptime which took this into account
    [communication.py, embeded_ntptime.py, main.py]
2017-12-16 Fixed minor typos in functions names
    [communication.py]
2017-12-16 Fixed minor bug with settime
    [communication.py]
2017-12-18 Alows to write varibales in flash memory
    Module was tested and works on the esp32
2017-12-18 Added some error management
    Impoemeted the handeling of various connection errors
    [communication.py, main.py]
2017-12-18 Added LED
    LED is red if module is awake and not setup
    LED is green if module is awake and setup
    LED is off when module sleeps
2017-12-18 Better LED managment
    GREEN: all works fine
    ORANGE: try to connect
    RED: waiting for configuration or connection failed
    [communication.py, main.py]
2017-12-18 Implemented server communication errors
    [communication.py, main.py]
2017-12-19 Added some correction factors
    [sensors.py]
2017-12-21 Fixed minor bugs, implemented fatal error
    Fatal error is implemented with a master try catch
    [communication.py, main.py]
2017-12-21 Added some debug prints
2017-12-22 Fixed minor bug
    Working code
    [main.py]
2017-12-22 Corrected water vollume
    added a few lines to adapte the watering time
    [main.py]
2017-12-25 Few adjustments
    Mostly easthetic adjusments. Plus chaged a few errors to have a more consistant error handeling
    [communication.py, main.py]
